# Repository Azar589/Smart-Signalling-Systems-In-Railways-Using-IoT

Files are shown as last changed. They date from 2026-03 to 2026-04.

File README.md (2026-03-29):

Here is a comprehensive and professionally structured README file for your project, incorporating all the provided details and code logic.

***

# Smart Signalling Systems in Railways

**Author**: Mohamed Azarudeen F.

## 📖 Abstract
The Smart Signalling System for Railways addresses critical visibility challenges faced by locomotive pilots, especially during adverse weather conditions such as fog and rain. The project introduces an advanced signalling solution using RF transceiver technology to ensure reliable, real-time communication between trackside signals and locomotives. 

By integrating RF transceivers with microcontrollers (ESP32 and Arduino Nano), trackside signal data is transmitted directly to a display monitor inside the train, entirely eliminating the dependency on visual cues. This system significantly enhances safety, reduces travel delays, and minimizes human error. Built with a focus on scalability, cost-effectiveness, and future IoT integration, it aligns with multiple UN Sustainable Development Goals by emphasizing innovation, safety, and infrastructure development.

## ✨ Key Features
* **Real-Time RF Communication**: Sends trackside status updates (RED, YELLOW, GREEN) to the locomotive instantaneously upon status change.
* **Robust Security Protocols**: Implements an XOR cipher with a predefined secret key (`0x5A`) for encrypting payload data.
* **Anti-Replay Attack Protection**: Utilizes incrementing sequence numbers to validate incoming packets and reject malicious replay attempts.
* **Device Authentication**: Enforces strict verification using a unique Device ID (`TX1`) to ensure the receiver only processes data from authorized trackside transmitters.
* **IoT Cloud Integration**: Securely uploads validated signal data to the ThingSpeak cloud platform over WiFi, utilizing a 16-second rate limit to comply with API constraints.
* **Local Web Dashboard**: Includes a custom Node.js server to host a real-time web monitoring dashboard (`Signal_Monitor_Web.html`) over port 8080.

## 🛠️ Hardware Requirements
* **Microcontrollers**: ESP32 (for the Receiver/Locomotive unit with WiFi capabilities) and Arduino Nano (for the Transmitter/Trackside unit).
* **Communication**: RF Transceiver modules compatible with the `RH_ASK` library.
* **Sensors/Indicators**: Trackside signal switches/sensors and corresponding LEDs for local status visualization.

## 💻 System Architecture

### 1. Transmitter Unit (`Tx_Unit.cpp`)
Located at the trackside, this unit reads digital inputs representing the current signal status (RED, YELLOW, GREEN). It monitors for state changes to reduce unnecessary RF traffic. When a change is detected, it formats a comma-separated payload containing the Device ID, an incrementing Sequence Number, and the Signal Status. The payload is then encrypted via XOR cipher and broadcasted over RF.

### 2. Receiver Unit (`Rx_Unit.cpp`)
Located inside the locomotive, this unit continuously listens for RF transmissions. Upon receiving a packet, it decrypts the string and extracts the comma-separated values. The unit verifies the `DEVICE_ID` and ensures the sequence number is strictly greater than the previously recorded sequence to prevent replay attacks. If valid, the new status is printed to the serial monitor and uploaded to a ThingSpeak channel via an HTTP GET request.

### 3. Web Dashboard Server (`server.js`)
A lightweight Node.js web server that serves the UI files (`.html`, `.css`, `.js`). Once started, it listens on port 8080 and provides a centralized interface for monitoring the IoT data sent by the trains. 

## 🚀 Installation and Setup

### Embedded Code Setup (Arduino IDE)
1.  **Dependencies**: Install the required C++ libraries via the Arduino Library Manager:
    * `RH_ASK` (RadioHead library for RF communication)
    * `WiFi` and `HTTPClient` (For ESP32 IoT connectivity)
2.  **Configuration**: 
    * In `Rx_Unit.cpp`, update the WiFi credentials (`WiFi.begin("SSID", "PASSWORD");`) to match your network.
    * Ensure your ThingSpeak API key is correctly set in the `thingSpeakWrite()` function URL.
3.  **Flashing**: Upload `Tx_Unit.cpp` to the Arduino Nano and `Rx_Unit.cpp` to the ESP32 using a baud rate of `115200`.

### Web Server Setup
1.  Navigate to the `Website` directory containing `server.js`.
2.  Ensure Node.js is installed on your machine.
3.  Run the server from the terminal:
    ```bash
    node server.js
    ```
4.  Open a browser and navigate to `http://localhost:8080` to access the dashboard.

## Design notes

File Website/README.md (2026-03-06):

Project Name - Smart Signalling Systems in Railways

Abstract :

      The Smart Signalling System for Railways addresses critical visibility challenges faced by locomotive pilots, especially during adverse weather conditions such as fog and rain. The project introduces an advanced signalling solution using RF transceiver technology to ensure reliable, real-time communication between trackside signals and locomotives. RF transceivers are integrated with microcontrollers (ESP32 and Arduino Nano) to transmit signal data to a display monitor inside the train, eliminating dependency on visual cues. This system significantly enhances safety, reduces travel delays, and minimizes human error by providing clear, continuous signal visibility. With a focus on scalability, cost-effectiveness, and future IoT integration, the proposed system represents a vital step towards modernising railway infrastructure and improving transportation reliability. The system also aligns with multiple UN Sustainable Development Goals, emphasising innovation, safety, and infrastructure development.

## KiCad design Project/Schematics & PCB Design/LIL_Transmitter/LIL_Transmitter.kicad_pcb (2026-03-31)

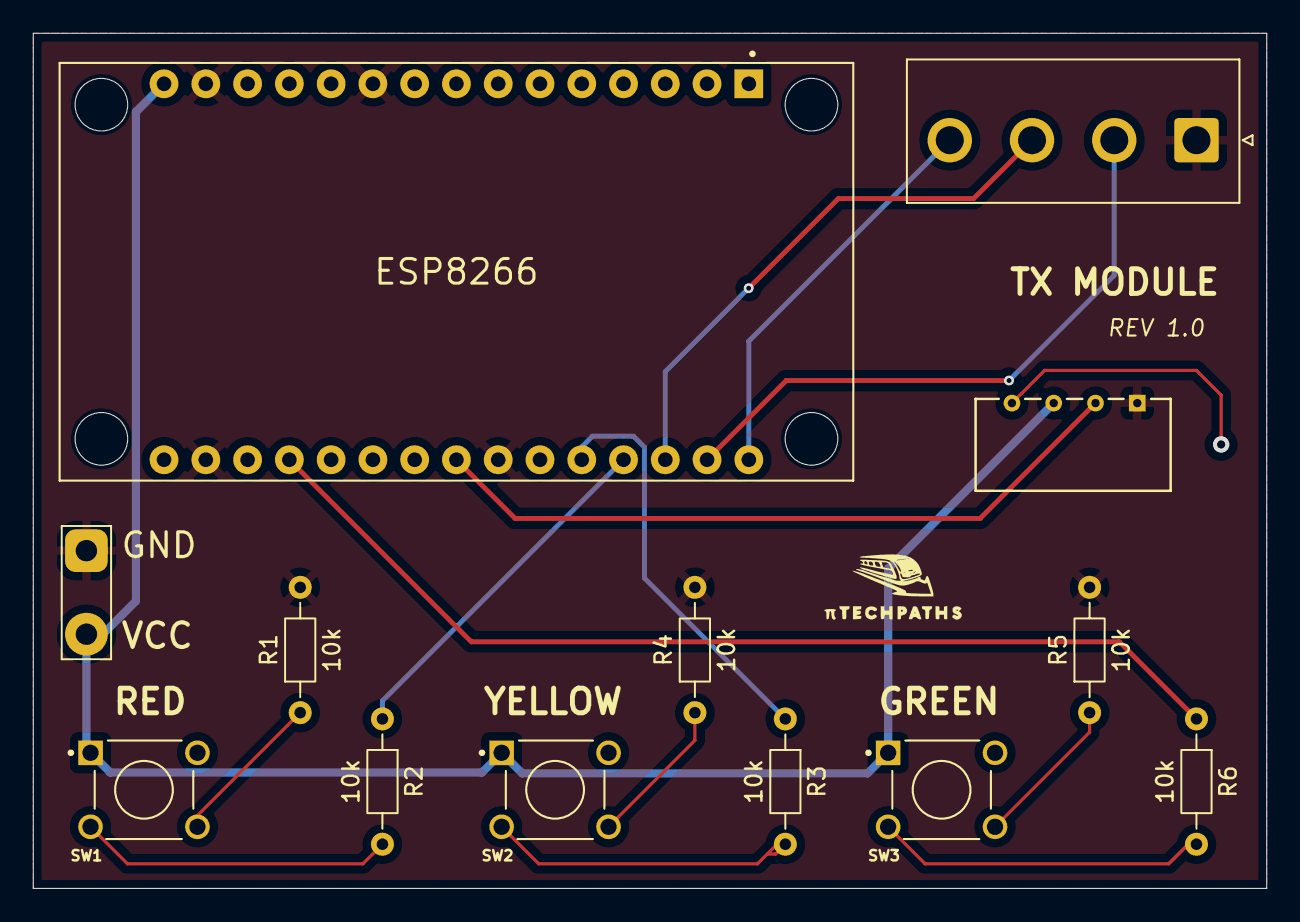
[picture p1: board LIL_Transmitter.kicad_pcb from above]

Board: 2 copper layers, 75.0 x 52.0 mm, 13 parts (0 on the bottom side), 15 nets.

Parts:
J1: OUTPUT; JST_NV_B04P-NV_1x04_P5.00mm_Vertical
R1, R2, R3, R4, R5, R6: 10k; R_Axial_DIN0204_L3.6mm_D1.6mm_P7.62mm_Horizontal
SW1, SW2, SW3: 1825910-6; SW_1825910-6-4
TP1: INPUT; TestPoint_2Pads_Pitch5.08mm_Drill1.3mm
U1: QAM-TX2-433; QAM-TX2-433_RFS
U2: ESP8266; MODULE_ZC563900

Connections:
/DAT: U1.2 (IN), U2.23 (D5)
/G: R6.1, U2.19 (RX)
/G1: J1.4, U2.30 (D0)
/R: R2.1, U2.27 (D3)
/R1: J1.2, U2.29 (D1)
/Y: R3.1, U2.26 (D4)
/Y1: J1.3, U2.28 (D2)
GND: J1.1, R1.2, R4.2, R5.2, TP1.1, U1.1 (GND), U2.10 (GND), U2.14 (GND), U2.17 (GND), U2.24 (GND)
unnamed: R1.1, SW1.4
unnamed: R2.2, SW1.3
unnamed: R3.2, SW2.3
unnamed: R4.1, SW2.4
unnamed: R5.1, SW3.4
unnamed: R6.2, SW3.3
VCC: SW1.1, SW2.1, SW3.1, TP1.2, U1.3 (VCC), U2.15 (VIN)

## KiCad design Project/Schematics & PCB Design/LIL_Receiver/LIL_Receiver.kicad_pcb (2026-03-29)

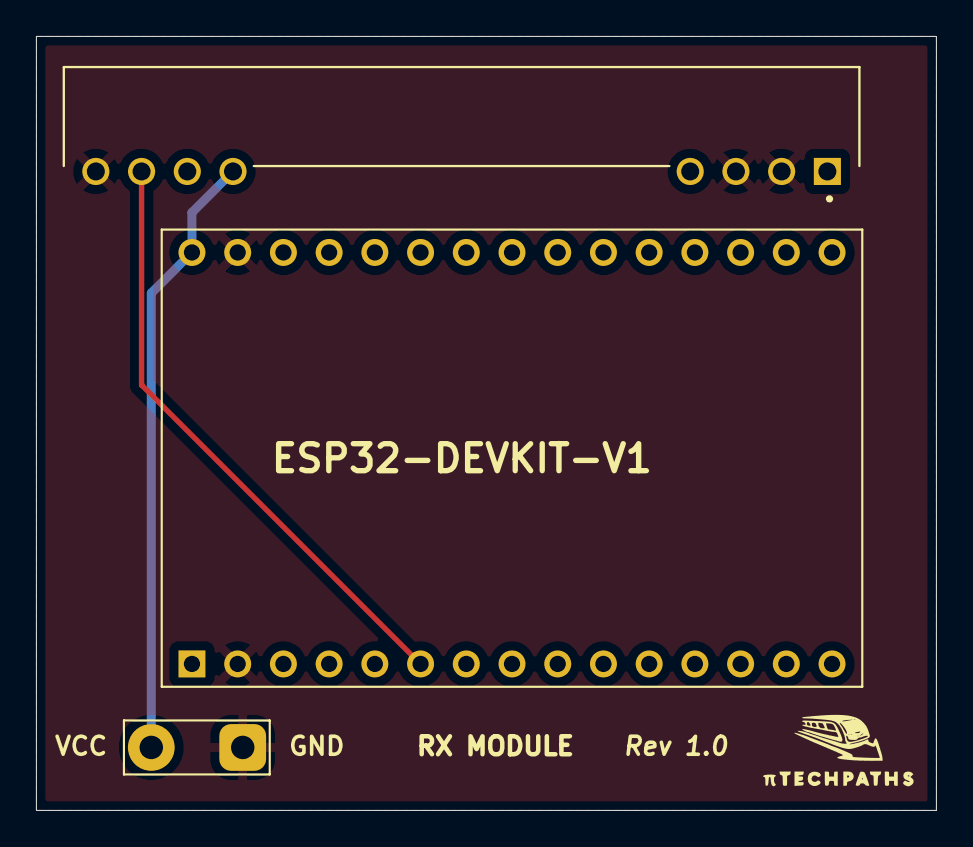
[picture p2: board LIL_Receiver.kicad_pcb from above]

Board: 2 copper layers, 50.0 x 43.0 mm, 3 parts (0 on the bottom side), 3 nets.

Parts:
TP1: INPUT; TestPoint_2Pads_Pitch5.08mm_Drill1.3mm
U1: ESP32-DEVKIT-V1; ESP32-C3-DevKitM-1
U2: QFM-RX1-433; MODULE_QFM-RX1-433

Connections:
/DAT: U1.6 (RX2), U2.7 (DATA_OUTPUT)
GND: TP1.1, U1.2 (GND), U1.29 (GND), U2.2 (GROUND), U2.3 (GROUND), U2.8 (GROUND)
VCC: TP1.2, U1.30 (VIN), U2.4 (SUPPLY_VOLTAGE), U2.5 (SUPPLY_VOLTAGE)

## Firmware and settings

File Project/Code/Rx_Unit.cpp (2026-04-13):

#include <RH_ASK.h>
#include <SPI.h>
#include <WiFi.h>
#include <HTTPClient.h>

RH_ASK rf_driver(2000, 16, -1, -1);
WiFiClient client;
HTTPClient http;

const long uploadInterval = 16000;           // 16s rate limit for ThingSpeak
unsigned long lastUploadTime = -uploadInterval; // Ensures first upload is never rate-limited
unsigned int lastSeqNum = 0;                  // Tracks the last received sequence

// Security Credentials
const char XOR_KEY = 0x5A; // Must match Tx unit
const String EXPECTED_ID = "TX1";

const String THINGSPEAK_API_KEY = "12WTGAIJQYNRUL22"; // ThingSpeak Write API Key

void encryptDecrypt(char* data, int len) {
  for(int i = 0; i < len; i++) {
    data[i] ^= XOR_KEY;
  }
}

void ConnectToWIFI() {
  WiFi.mode(WIFI_STA);
  WiFi.begin("Azar's M34", "azar@2005");
  while (WiFi.status() != WL_CONNECTED) {
    delay(500);
    Serial.print(".");
  }
  Serial.println("\nWiFi Connected!");
}

void thingSpeakWrite(String data) {
  // FIX 3: Check rate limit BEFORE receiving — log and skip clearly if throttled
  unsigned long now = millis();
  if (now - lastUploadTime < uploadInterval) {
    unsigned long remaining = uploadInterval - (now - lastUploadTime);
    Serial.println("Rate limited. Skipping upload. Retry in " + String(remaining / 1000) + "s. Data: " + data);
    return;
  }

  if (WiFi.status() != WL_CONNECTED) {
    Serial.println("WiFi disconnected! Attempting reconnect...");
    ConnectToWIFI();
  }

  String url = "http://api.thingspeak.com/update?api_key=" + THINGSPEAK_API_KEY + "&field1=" + data;
  http.begin(client, url);
  int httpcode = http.GET();

  // FIX 4: Properly validate the HTTP response code
  if (httpcode == 200) {
    String response = http.getString();
    if (response.toInt() > 0) {
      Serial.println("Cloud Sync Successful | Entry#: " + response + " | Data: " + data);
      lastUploadTime = millis(); // Only update timer on confirmed success
    } else {
      // ThingSpeak returns "0" when the update was rejected (e.g. same data, rate limit)
      Serial.println("Cloud Upload Rejected by ThingSpeak (returned 0). Data: " + data);
    }
  } else {
    Serial.println("Cloud Upload Failed! HTTP Code: " + String(httpcode) + " | Data: " + data);
  }
  http.end();
}

void setup() {
  Serial.begin(115200);
  rf_driver.init();
  ConnectToWIFI();
}

void loop() {
  uint8_t buf[RH_ASK_MAX_MESSAGE_LEN + 1];
  uint8_t buflen = sizeof(buf) - 1;

  if (rf_driver.recv(buf, &buflen)) {
    buf[buflen] = '\0';

    // 1. Decrypt the incoming data
    encryptDecrypt((char*)buf, buflen);
    String payload = (char*)buf;

    // 2. Parse the payload (Looking for commas)
    int firstComma = payload.indexOf(',');
    int secondComma = payload.indexOf(',', firstComma + 1);

    if (firstComma > 0 && secondComma > 0) {
      String deviceID = payload.substring(0, firstComma);
      unsigned int recSeqNum = payload.substring(firstComma + 1, secondComma).toInt();
      String statusData = payload.substring(secondComma + 1);

      // 3. Authenticate Device ID and verify it's a new message (Anti-Replay)
      if (deviceID == EXPECTED_ID) {
        // FIX 2: Removed '|| lastSeqNum == 0' — it allowed replay attacks on boot.
        // lastSeqNum starts at 0 and TX starts at seqNum=1, so first valid packet will
        // always pass (1 > 0) without needing the bypass condition.
        if (recSeqNum > lastSeqNum) {
          Serial.println("Validated [Seq:" + String(recSeqNum) + "]: " + statusData);
          lastSeqNum = recSeqNum; // Save the new sequence number
          thingSpeakWrite(statusData); // Push to cloud
        } else {
          Serial.println("Blocked: Replay Attack Detected. Received Seq=" + String(recSeqNum) + " Last=" + String(lastSeqNum));
        }
      } else {
        Serial.println("Blocked: Unknown Device ID: " + deviceID);
      }
    } else {
      Serial.println("Blocked: Malformed or Corrupted Packet: " + payload);
    }
  }
}

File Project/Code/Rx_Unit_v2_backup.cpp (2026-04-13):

#include <RH_ASK.h>
#include <SPI.h>
#include <WiFi.h>
#include <HTTPClient.h>

RH_ASK rf_driver(2000, 16, -1, -1);
WiFiClient client;
HTTPClient http;

// ─────────────────────────────────────────
//  ThingSpeak Config
// ─────────────────────────────────────────
const String THINGSPEAK_API_KEY = "12WTGAIJQYNRUL22"; // ThingSpeak Write API Key
const long   UPLOAD_INTERVAL    = 16000;               // 16s (ThingSpeak free tier limit)

// ─────────────────────────────────────────
//  Data Queue (Buffer)
// ─────────────────────────────────────────
const int    QUEUE_SIZE  = 20;          // Max 20 pending entries
String       queue[QUEUE_SIZE];         // Stores signal status strings
int          queueHead   = 0;           // Next item to send
int          queueTail   = 0;           // Next empty slot to write
int          queueCount  = 0;           // Current items in queue

unsigned long lastUploadTime = -UPLOAD_INTERVAL; // First upload never rate-limited

// ─────────────────────────────────────────
//  Security
// ─────────────────────────────────────────
const char   XOR_KEY     = 0x5A;        // Must match Tx unit
const String EXPECTED_ID = "TX1";
unsigned int lastSeqNum  = 0;

// ─────────────────────────────────────────
//  Queue Operations
// ─────────────────────────────────────────
bool enqueue(String data) {
  if (queueCount >= QUEUE_SIZE) {
    Serial.println("⚠ Queue Full! Dropping oldest entry: " + queue[queueHead]);
    // Drop oldest to make room for newest
    queueHead = (queueHead + 1) % QUEUE_SIZE;
    queueCount--;
  }
  queue[queueTail] = data;
  queueTail = (queueTail + 1) % QUEUE_SIZE;
  queueCount++;
  Serial.println("Queued [" + String(queueCount) + "/" + String(QUEUE_SIZE) + "]: " + data);
  return true;
}

String dequeue() {
  if (queueCount == 0) return "";
  String data = queue[queueHead];
  queue[queueHead] = "";             // Clear the slot
  queueHead = (queueHead + 1) % QUEUE_SIZE;
  queueCount--;
  return data;
}

// ─────────────────────────────────────────
//  Decryption
// ─────────────────────────────────────────
void encryptDecrypt(char* data, int len) {
  for (int i = 0; i < len; i++) {
    data[i] ^= XOR_KEY;
  }
}

// ─────────────────────────────────────────
//  WiFi
// ─────────────────────────────────────────
void ConnectToWIFI() {
  WiFi.mode(WIFI_STA);
  WiFi.begin("Azar's M34", "azar@2005");
  while (WiFi.status() != WL_CONNECTED) {
    delay(500);
    Serial.print(".");
  }
  Serial.println("\nWiFi Connected!");
}

// ─────────────────────────────────────────
//  Cloud Upload (sends ONE item from queue)
// ─────────────────────────────────────────
void processQueue() {
  if (queueCount == 0) return; // Nothing to send

  unsigned long now = millis();
  if (now - lastUploadTime < UPLOAD_INTERVAL) return; // Rate limit not expired yet

  if (WiFi.status() != WL_CONNECTED) {
    Serial.println("WiFi disconnected! Reconnecting...");
    ConnectToWIFI();
  }

  String data = dequeue(); // Take one item from the front
  if (data == "") return;

  String url = "http://api.thingspeak.com/update?api_key=" + THINGSPEAK_API_KEY + "&field1=" + data;
  http.begin(client, url);
  int httpcode = http.GET();

  if (httpcode == 200) {
    String response = http.getString();
    if (response.toInt() > 0) {
      Serial.println("✔ Cloud Sync OK | Entry#: " + response + " | Data: " + data
                     + " | Queue Remaining: " + String(queueCount));
      lastUploadTime = millis(); // Reset timer only on success
    } else {
      // ThingSpeak rejected — requeue the item so it's not lost
      Serial.println("✘ Rejected by ThingSpeak (returned 0). Requeueing: " + data);
      enqueue(data);
    }
  } else {
    // Network error — requeue the item so it's not lost
    Serial.println("✘ HTTP Error: " + String(httpcode) + ". Requeueing: " + data);
    enqueue(data);
  }
  http.end();
}

// ─────────────────────────────────────────
//  Setup
// ─────────────────────────────────────────
void setup() {
  Serial.begin(115200);
  rf_driver.init();
  ConnectToWIFI();
  Serial.println("RX Unit v2 Ready (Queue Mode).");
}

// ─────────────────────────────────────────
//  Main Loop
// ─────────────────────────────────────────
void loop() {
  // ── 1. Receive RF data ──
  uint8_t buf[RH_ASK_MAX_MESSAGE_LEN + 1];
  uint8_t buflen = sizeof(buf) - 1;

  if (rf_driver.recv(buf, &buflen)) {
    buf[buflen] = '\0';

    encryptDecrypt((char*)buf, buflen);
    String payload = (char*)buf;

    int firstComma  = payload.indexOf(',');
    int secondComma = payload.indexOf(',', firstComma + 1);

    if (firstComma > 0 && secondComma > 0) {
      String       deviceID   = payload.substring(0, firstComma);
      unsigned int recSeqNum  = payload.substring(firstComma + 1, secondComma).toInt();
      String       statusData = payload.substring(secondComma + 1);

      if (deviceID == EXPECTED_ID) {
        if (recSeqNum > lastSeqNum) {
          Serial.println("Validated [Seq:" + String(recSeqNum) + "]: " + statusData);
          lastSeqNum = recSeqNum;
          enqueue(statusData); // ← Store in queue instead of direct upload
        } else {
          Serial.println("Blocked: Replay Attack. Seq=" + String(recSeqNum) + " Last=" + String(lastSeqNum));
        }
      } else {
        Serial.println("Blocked: Unknown Device ID: " + deviceID);
      }
    } else {
      Serial.println("Blocked: Malformed Packet: " + payload);
    }
  }

  // ── 2. Upload from queue every 16s ──
  processQueue();
}

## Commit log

2026-03-06 Added project overview for Smart Signalling System
    The README introduces the Smart Signalling System for Railways, detailing its purpose, technology, and benefits.
2026-03-29 Files Organized and Schematics & PCB Designs added
    [LIL_Receiver.kicad_pcb, LIL_Receiver.kicad_sch, LIL_Transmitter.kicad_pcb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]
2026-03-30 Tx Code Optimized for board safety concerns
2026-03-31 Schematics & PCB Designs Updated
    [LIL_Transmitter.kicad_pcb, LIL_Transmitter.kicad_sch]
2026-04-13 Rx Unit bug cleared and Rx unit version 2 uploded
    [Rx_Unit.cpp]
